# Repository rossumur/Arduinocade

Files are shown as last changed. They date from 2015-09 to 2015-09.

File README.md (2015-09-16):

#Arduinocade
Play retro color 8 bit games on your TV from an Arduino.

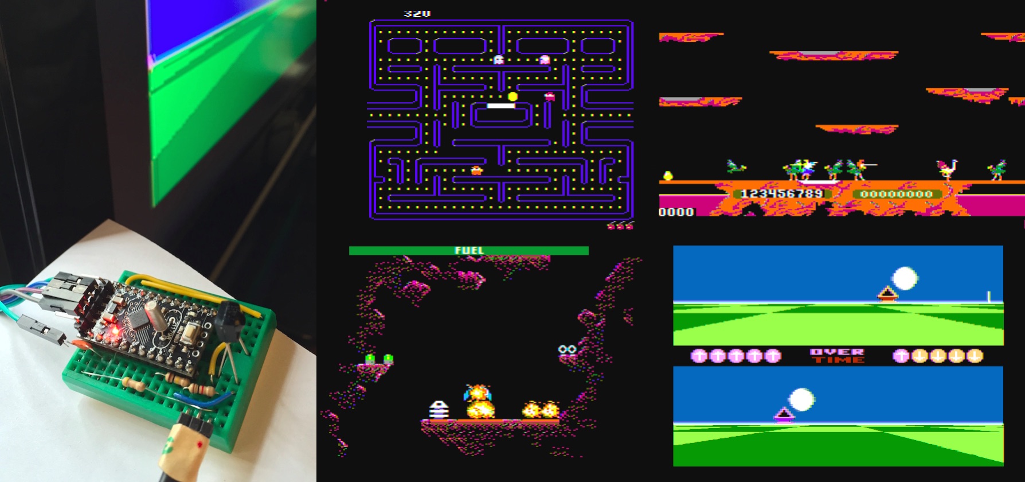
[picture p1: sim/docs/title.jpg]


**Arduinocade** features old school color 8 bit graphics (tiles, sprites, smooth scrolling, simple 3D) and sound (4 voice wavetable synthesis). All video and audio signals are generated with three resistors, an upgraded crystal and a little software. By overclocking the Arduino to 28.6363Mhz we can directly manipulate NTSC to generate 27 simultaneous colors. An IR receiver supports a wide variety of keyboards, joysticks and remote controls.

Video of Arduinocade in action at https://www.youtube.com/watch?v=nGIujZiEu_o

##Games
These games are sketches of what is possible on the Arduinocade hardware and a far from the polished pieces that inspired them.

###Ballblaster
A one-on-one sports style game inspired by the brilliant 1984 game Ballblazer. This uses a simple physics model and a 2D/3D rendering pipeline to produce 60fps animation. Try and grab the ball and shoot it into your opponent's goal.

###Pacman
What can I say? pakku pakku pakku.

###Jowst
Fly around on ostrich thingys. Poke each other with sticks. Nice example of using the sprite engine to generate lots of large multicolor sprites.

###Caverns of Titan
Homage to the Atari classic “Caverns of Mars”. Smooth scrolling, sprites and animation.

##Building the Hardware
Lots of different ways to build this beastie. The design is simple enough to build on a breadboard with a DIP Atmega328, alternatively you might want to add a 28.6363Mhz crystal to a $2 Arduino Pro Mini or even build on a custom PCB. 

###You will need
+ Arduino Pro Mini, Atmega328p or equivalent
+ 28.6363Mhz Crystal (from Adafruit, eBay etc)
+ RCA Audio/Video Cable (eBay)
+ 470ohm, 1k and 100k resistors
+ IR receiver TSOP38238,TSOP4838 or equivalent (Adafruit, Mouser etc)
+ IR Input device (see below)

```
        +----------------+
        |    arduino     |
        |    uno/pro     |
        |     28Mhz      |       5v <--+-+   IR Receiver
        |                |      GND <--|  )  TSOP4838
        |              8 |-------------+-+
        |                |
        |              6 |----[ 100k ]--------> AUDIO
        |                |
        |              9 |----[  1k  ]----+---> VIDEO
        |                |                |
        |              1 |----[ 470  ]----+
        |                |
        |              3 |
        |              2 |
        |                |
        +----------------+
```

###Mini Pro
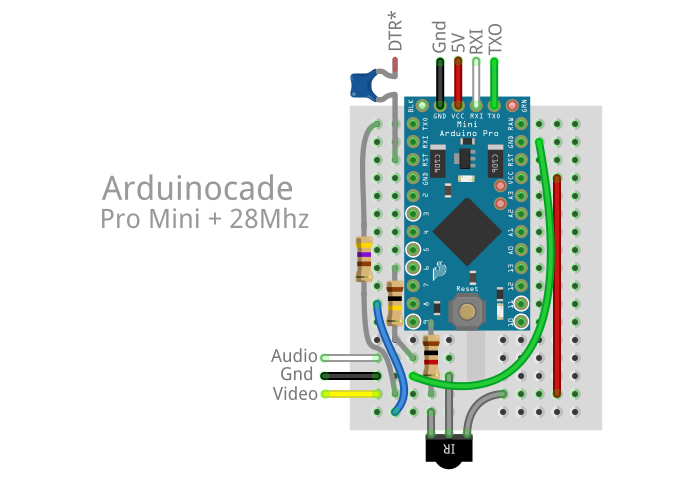
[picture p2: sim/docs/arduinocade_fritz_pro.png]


We will be upgrading the crystal/resonator on these boards from 16Mhz to 28.6363Mhz. The easiest ones to modify have the big silver cans on them. Others use a ceramic resonator which require a bit of SMD fiddling.

###Custom PCB
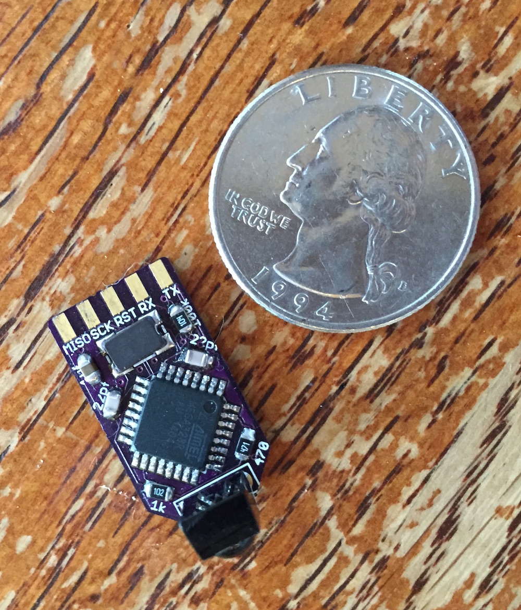
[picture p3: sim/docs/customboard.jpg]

If you want to get silly and build a custom board you can get a video console down to about the size of a quarter. Board and schematics can be found in `sim/docs/eagle`.

##Input Devices
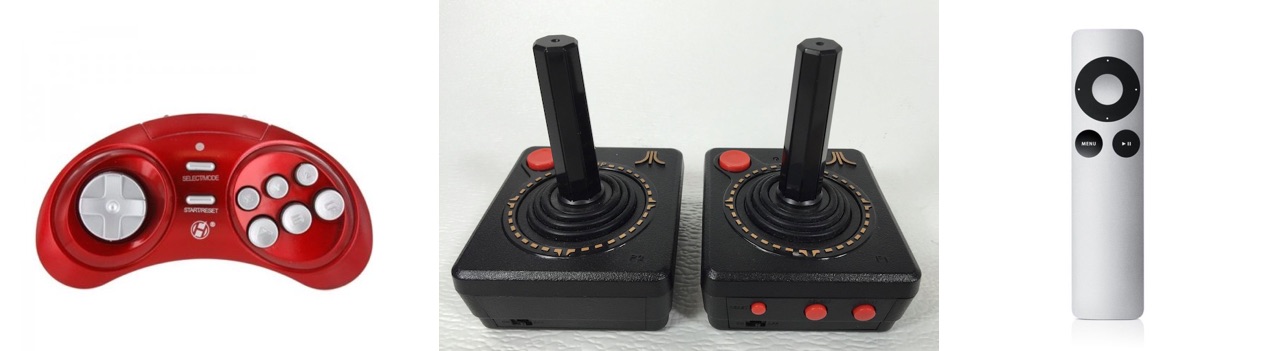
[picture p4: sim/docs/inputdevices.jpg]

*Retcon IR Controller, Atari Flashback 4 joysticks, Apple TV remote*

A number of IR input devices are supported. The IR Wireless Controllers from Atari Flashback 4 work well and have that classic joystick feel, as do the Retron IR controllers. These can be readily found on eBay for a few bucks. The Apple TV remote is also supported by you might feel a little silly. Edit config.h to select your input of choice.

##Upgrading the bootloader
If you want to use the Arduino IDE you should upgrade the bootloader to be able to work at 115200 baud with the faster crystal installed. The optiboot_atmega32_28.hex image has been rebuilt with F_CPU=28636363 and a slower watchdog reset so baud rate calculations will be correct for our overclocked device. Install the image with avrdude and your favorite ISP.
```
avrdude -c usbtiny -p atmega328p -e -u -U lock:w:0x3f:m -U efuse:w:0x05:m -U hfuse:w:0xDE:m -U lfuse:w:0xFF:m
avrdude -c usbtiny -p atmega328p -U flash:w:optiboot_atmega328_28Mhz.hex -U lock:w:0x0f:m
```
Once the modified optiboot is installed the device will behave like an Uno, so remember to select that from the boards menu in the Arduino IDE.

##Using the Arduino IDE

>**Note:**
>The current code does not work correctly with Arduino IDEs later than 1.5.6. Compiler optimizations in later versions interfere with hand timed loops in the video kernels. I will fix soon.

Copy the `Arduinocade` folder into the IDE libraries folder and relaunch IDE. You should be able to open the example games from *File->Examples->Arduinocade*. Edit the config.h file to enable or disable the custom `BALLBLASTER_GAME` kernel.

##How it works

###Video
Upgrading the crystal to 28.6363Mhz allows us to run at a multiple (8x CPU clock, 4x SPI output) of the NTSC subcarrier frequency. By spitting out bits in the right pattern at the right time we can generate NTSC colorburst and different colors based on the relative phase of the pattern.

Black (0000), White (1111), gray_5 (0101) and gray_10 (1010) don’t have a chroma component; the other 12 colors do. By inserting or skipping an extra nop in rendering kernel we can select between two different phases at the start of a line yielding 12+12+(black,white,gray) = 27 simultaneous colors on screen simultaneously. You can then add more by dithering etc.

###The Art of Artifacts
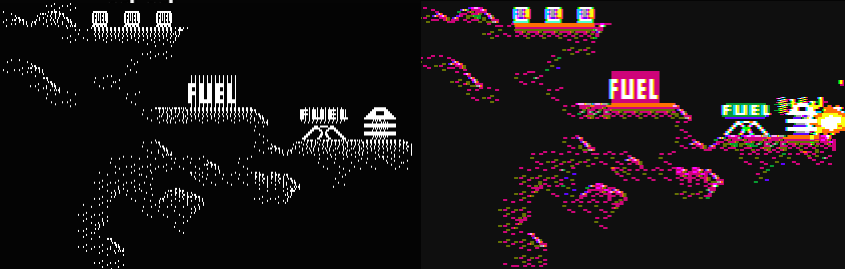
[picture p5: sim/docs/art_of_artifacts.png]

*Left - Pixels being emitted from the TX port, Right - Colors as they appear on NTSC* 

Every HSYNC interrupt the cpu emits a 3.57Mhz colorburst signal then sends pixel data from carefully timed tile or RLE video kernels. These are tricky to maintain in C, as helpful compiler optimizations often alter timing in unexpected ways. They probably all need to move to asm at some point. See note above.

The higher layer code uses a RLE format (BallBlaster) or tiles to represent game content. Because we don’t have enough memory for a full frame buffer individual lines of tiles and sprites are composed in a loop that is in lock step with the HSYNC interrupt.

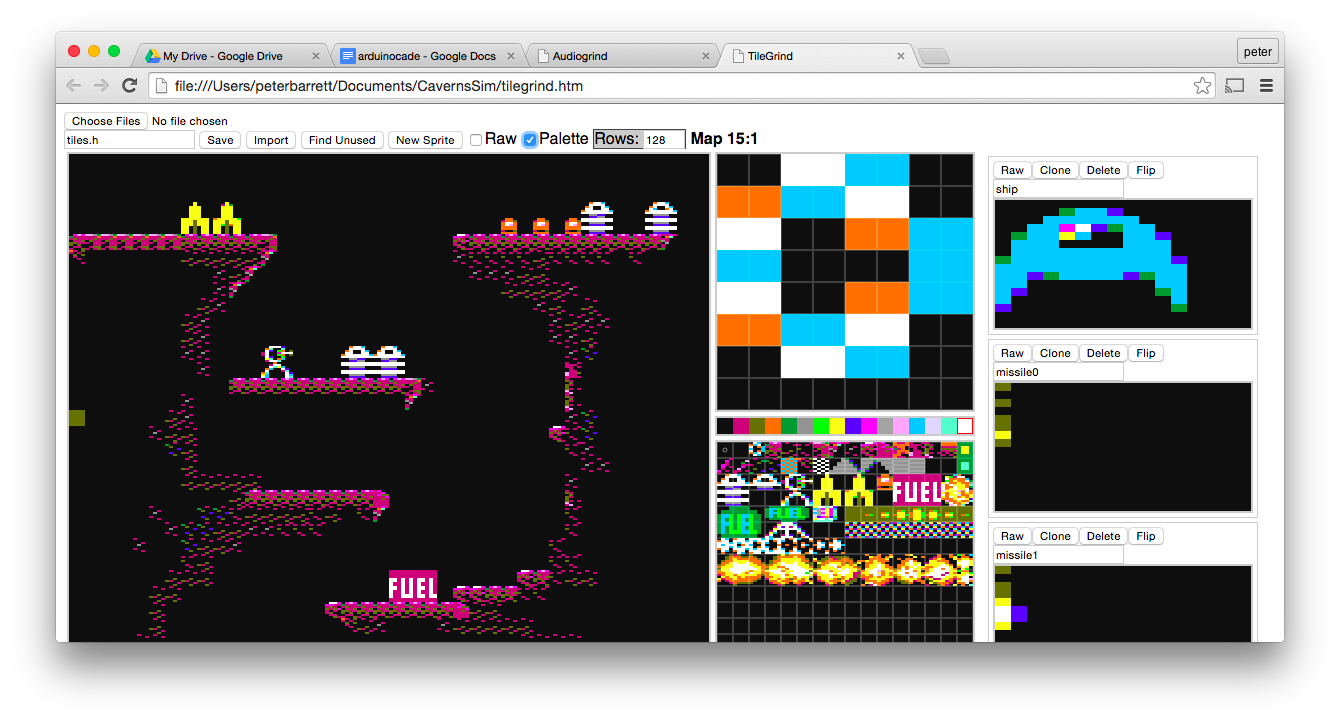
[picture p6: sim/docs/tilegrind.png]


TileGrind is a primitive html/javascript tool for generating color tiles and sprites. It can load and save C structs and understands the nature of NTSC color phase / artifacting. Its limitations vividly recreate the frustration of early graphics editing tools.

###Audio
The Audio driver has two parts.  The low level kernel runs every HSYNC, stepping each of the 4 voices though it’s wavetable, mixing the sampled voices together based on their current volume and emitting a sample to the PWM/resistor single bit DAC. This corresponds to a sample rate of 15734Hz.

The high level task runs every frame at 60Hz and adjusts envelope, modulates frequency of the underlying channels etc. It is responsible for parsing data structures containing music tracks and sound effects, adjusting volume envelopes and frequencies, swapping wavetables for different instruments etc.

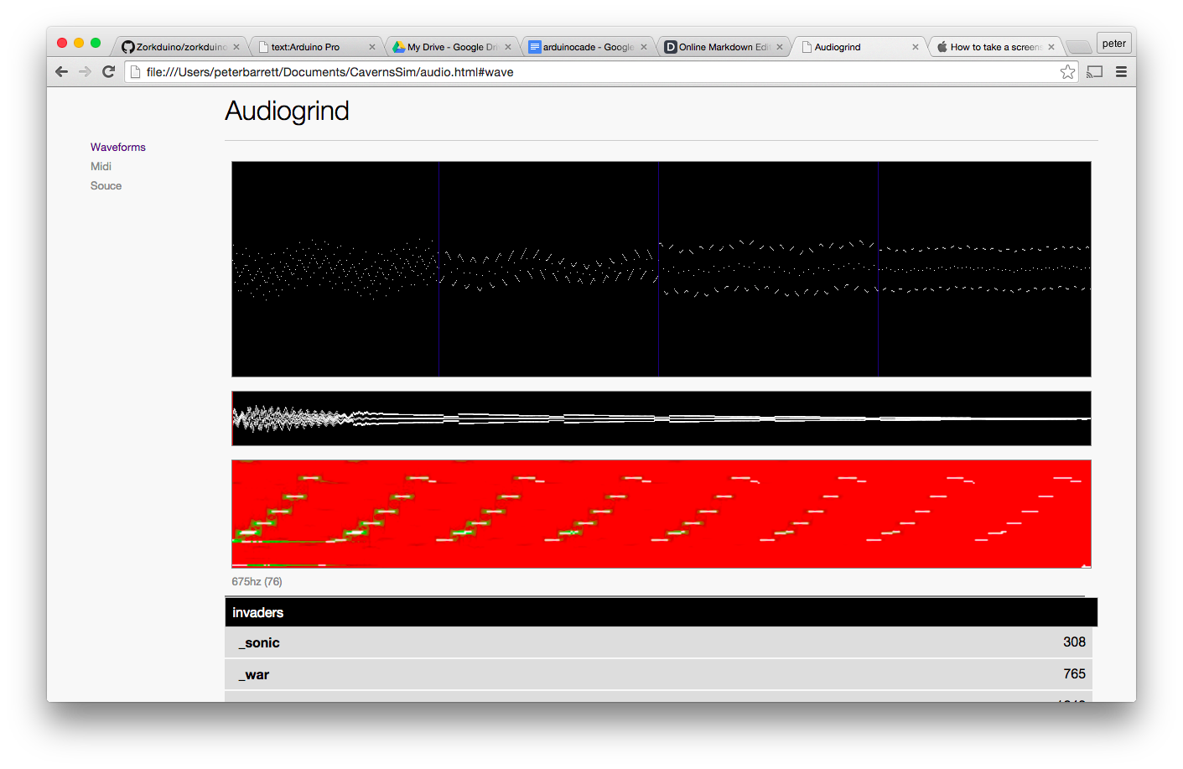
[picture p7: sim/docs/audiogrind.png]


AudioGrind is a primitive html/javascript audio editing tool is used to convert midi files to C struct data. It can also be used to reverse engineer classic gaming sound effects using a graphical spectrogram, without which it is nearly impossible to figure out how the effects are constructed - I’m talking to you Joust.

###IR input Joysticks, Keyboards etc
The GPIO attached to the IR sensor is sampled at HSYNC and fed to one of a number of IR decoders. The 15734Hz sample rate is enough to accurately parse nearly all IR protocols. For performance reasons only one is enabled at a time; check the #ifdefs in ir_input.cpp.

##So enjoy

Let me know if you have some fun with it.

Cheers
Rossum

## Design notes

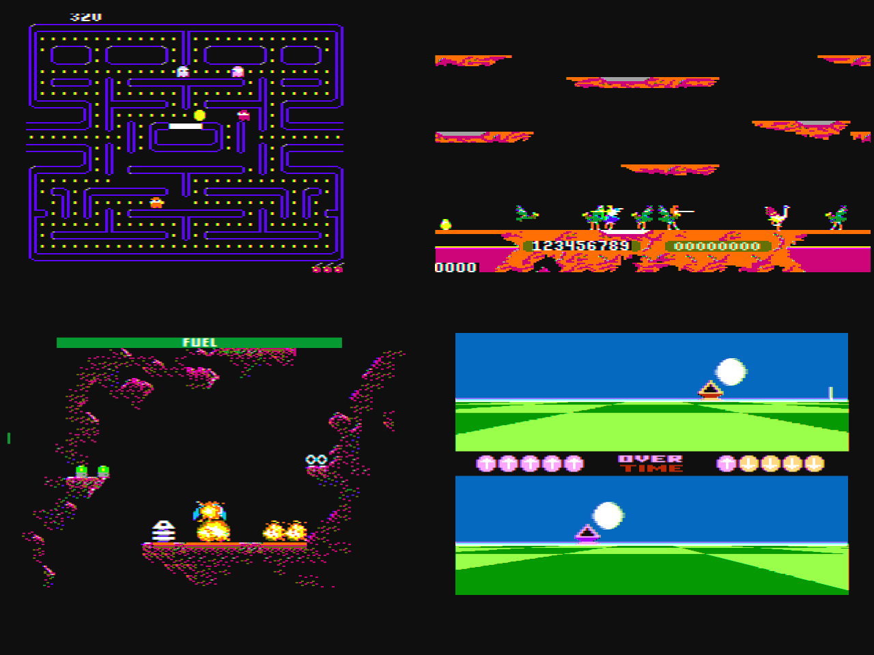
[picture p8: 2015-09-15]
sim/docs/screenshots.png

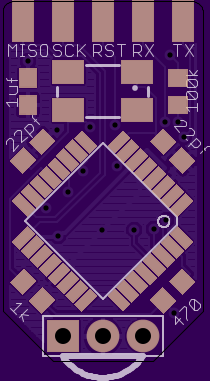
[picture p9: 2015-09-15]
sim/docs/pcb_top.png

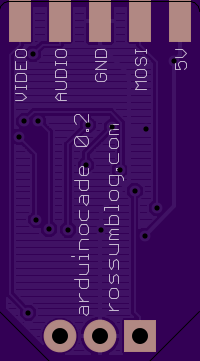
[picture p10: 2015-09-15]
sim/docs/pcb_bottom.png

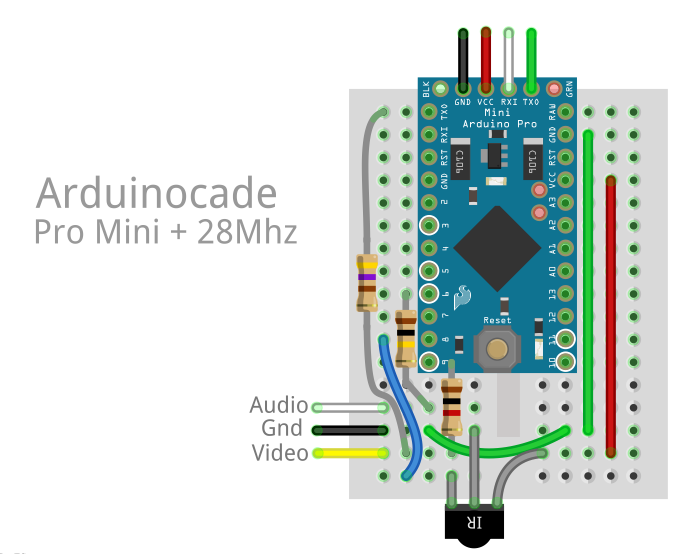
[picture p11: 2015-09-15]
sim/docs/arduinocade_friz_pro.png

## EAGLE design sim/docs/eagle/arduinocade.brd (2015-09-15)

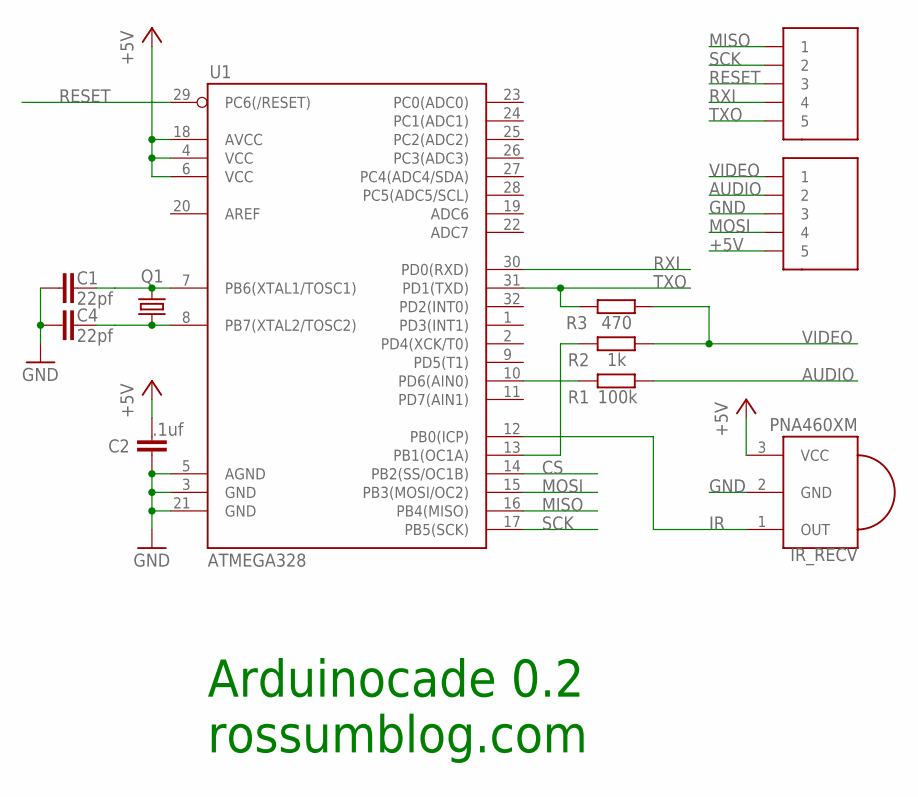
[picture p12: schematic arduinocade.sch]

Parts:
C1, C4: 22pf; C0603
C2: .1uf; C0603
IR_RECV: PNA460XM
Q1: CRYSTALCTS406; CTS406
R1: 100k; R0603
R2: 1k; R0603
R3: 470; R0603
U1: ATMEGA328; TQFP32-08
U$2, U$3: EDGE5

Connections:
+5V: C2.1, U1.4 (VCC), U1.6 (VCC), U1.18 (AVCC), U$3.5
AUDIO: R1.2, U$3.2
CS: U1.14 (PB2(SS/OC1B))
GND: C1.2, C2.2, C4.2, IR_RECV.2 (GND), U1.3 (GND), U1.5 (AGND), U1.21 (GND), U$3.3
IR: IR_RECV.1 (OUT), U1.12 (PB0(ICP))
MISO: U1.16 (PB4(MISO)), U$2.1
MOSI: U1.15 (PB3(MOSI/OC2)), U$3.4
unnamed: C4.1, Q1.1, U1.8 (PB7(XTAL2/TOSC2))
unnamed: C1.1, Q1.3 (2), U1.7 (PB6(XTAL1/TOSC1))
unnamed: R2.1, U1.13 (PB1(OC1A))
unnamed: R1.1, U1.10 (PD6(AIN0))
RESET: U1.29 (PC6(/RESET)), U$2.3
RXI: U1.30 (PD0(RXD)), U$2.4
SCK: U1.17 (PB5(SCK)), U$2.2
TXO: R3.1, U1.31 (PD1(TXD)), U$2.5
VCC: IR_RECV.3 (VCC)
VIDEO: R2.2, R3.2, U$3.1

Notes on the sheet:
Arduinocade 0.2
rossumblog.com

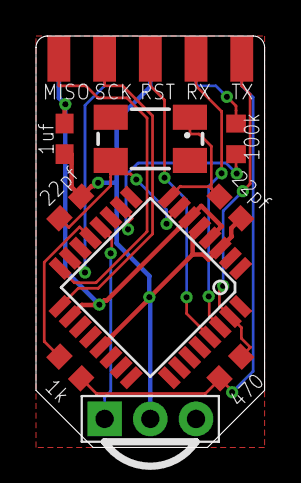
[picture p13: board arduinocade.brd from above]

Board: 2 copper layers, 12.7 x 22.9 mm, 11 parts (1 on the bottom side), 15 nets.

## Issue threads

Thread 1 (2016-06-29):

ATMEGA328PU

fredericplante, 2016-06-29:
Hey it's not really an issue, but before getting 28Mhz christal, I wounder, will that work on the DIP version of the ATMEGA328, or does it need to be done on a mini?

jameswilddev, 2020-12-31:
Should work on a DIP 328p:

```
##Building the Hardware Lots of different ways to build this beastie. The design is simple enough to build on a breadboard with a DIP Atmega328, alternatively you might want to add a 28.6363Mhz crystal to a $2 Arduino Pro Mini or even build on a custom PCB.
```

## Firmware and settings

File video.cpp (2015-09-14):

/* Copyright (c) 2010-2015, Peter Barrett
 **
 ** Permission to use, copy, modify, and/or distribute this software for
 ** any purpose with or without fee is hereby granted, provided that the
 ** above copyright notice and this permission notice appear in all copies.
 **
 ** THE SOFTWARE IS PROVIDED "AS IS" AND THE AUTHOR DISCLAIMS ALL
 ** WARRANTIES WITH REGARD TO THIS SOFTWARE INCLUDING ALL IMPLIED
 ** WARRANTIES OF MERCHANTABILITY AND FITNESS. IN NO EVENT SHALL THE AUTHOR
 ** BE LIABLE FOR ANY SPECIAL, DIRECT, INDIRECT, OR CONSEQUENTIAL DAMAGES
 ** OR ANY DAMAGES WHATSOEVER RESULTING FROM LOSS OF USE, DATA OR PROFITS,
 ** WHETHER IN AN ACTION OF CONTRACT, NEGLIGENCE OR OTHER TORTIOUS ACTION,
 ** ARISING OUT OF OR IN CONNECTION WITH THE USE OR PERFORMANCE OF THIS
 ** SOFTWARE.
 */

// Video output, audio tone generation and IR keyboard scanning events

#include "config.h"
#include "video.h"

// PORT B
#define SYNC_PIN    1
#define IR_PIN      0

// PORT D
#define AUDIO_PIN       6
#define PS2_CLOCK_PIN   3
#define PS2_DATA_PIN    2
#define VIDEO_PIN       1

// Color clock frequency is 315/88
// CPU Mhz is 315/11
// 455/2 color clocks per line
// HSYNCH period is 44/315*455 or 63.55555..us
// Field period is 262*44/315*455 or 16651.5555us

// ~1820 cpu clocks per line at 28.6363Mhz
#define USEC(_x)         (((_x)*28.6363)-1)
#define TICKS_SCANLINE   (1824-1)
#define TICKS_HSYNC      USEC(4.7)
#define TICKS_LONG_HSYNC USEC(63.555-4.7)
#define TICKS_HBLANK     USEC((4.7+1.5))
#define TICKS_INTERRUPT  USEC(4.05)  // late as possible 4.2

#define TEXT_ROWS 24
#define TEXT_COLS 40
#define BLANK_LINES 40
#define ACTIVE_LINES (TEXT_ROWS*8)

#define STATE_VBLANK  0
#define STATE_PRE     1
#define STATE_ACTIVE  2
#define STATE_POST    3

// does not do halfline sync during blanking
//__attribute__((section(".progmem.data")))
PROGMEM
const uint8_t v_lines[] = { 3,BLANK_LINES,ACTIVE_LINES,262-(3+BLANK_LINES+ACTIVE_LINES) };

// Video State
volatile uint8_t v_state = 0;
volatile uint8_t v_count = 0;
uint8_t v_vbicountdown = 0;

// TODO
uint8_t v_framecounter;
uint16_t _linecount;

// Audio state
uint8_t a_count = 0;
uint8_t a_freq = 0;
uint8_t a_cycles = 0;

// IR state
uint8_t ir_last = 0;
uint8_t ir_count = 0;

//==========================================================
//==========================================================
//  Webtv keyboard

// Report changes on IR pin to keyboard handler
// t is HSYNCH ticks
void keyboardIREvent(uint8_t t, uint8_t v);

//==========================================================
//==========================================================
// PS2 keyboard

void enable_ps2();
void disable_ps2();

//==========================================================
//==========================================================
//  audio for keyboard/io feedback

void audio_beep(uint8_t freq, uint8_t cycles)
{
    a_freq = freq;
    a_cycles = cycles;
    a_count = freq;
}

//==========================================================
//==========================================================
// Video buffering state machine

#define VROWS_BUFS   4 // POWER OF 2
#define VROWS_MASK (VROWS_BUFS-1)

volatile VRow* _vrows[VROWS_BUFS];
volatile uint8_t _vread;
volatile uint8_t _vwrite;

// TODO: 0..ACTIVE_LINES?
int video_current_line()
{
    if (v_state == STATE_ACTIVE)
        return ACTIVE_LINES-v_count;
    return v_state == STATE_POST ? ACTIVE_LINES : -1;
}

uint8_t video_queue_count()
{
    return _vwrite-_vread;
}

void video_enqueue(VRow* row)
{
    while (_vwrite-_vread == VROWS_BUFS)
        ; // Queue is full
    _vrows[_vwrite++ & VROWS_MASK] = row;
}

//==========================================================
//==========================================================
//  Video ISR

static void inline tick_align(uint8_t tick)
{
    __asm__ __volatile__ (
                          "sub	%[tick], %[tcnt1l]\n"
                          "0: subi	%[tick], 3\n"
                          "brcc	0b\n"
                          "cpi      %[tick],-3\n"
                          "breq     1f\n"
                          "cpi      %[tick],-2\n"
                          "brne     .\n"
                          "1:\n"
                          :: [tick] "a" (tick),
                          [tcnt1l] "a" (TCNT1L)
                          );
}

void rle_blit(VRowRLE* row)
{
    UDR0 = 0;
    uint8_t run = row->skip;
    uint8_t x = row->width;
    const uint8_t* rle = row->rle;
    if (!rle)
        return;
    uint8_t color = 0;
    
    //  16 clocks thru all paths
    for(;;)
    {
        UDR0 = color;          // 2
        asm ("nop");           // 1
        if (!--run)            // 1+(1:3)
        {
            if (!x)              // 1+(1:3)
                break;
            run = rle[0];        // 2
            color = rle[1];      // 2
            rle += 2;            // 2 (stupid)
            x-= run;             // 1
            continue;            // 3
        }
        asm ("nop");            // 1
        asm ("nop");            // 1
        asm ("nop");            // 1
        asm ("nop");            // 1
        asm ("nop");            // 1
        asm ("nop");            // 1
        asm ("nop");            // 1
        asm ("nop");            // 1
    }
}

#define BUFFER_SIZE 1350
#define MAX_LINE_BYTES 64
extern volatile uint8_t* _read_rle;
extern uint8_t _bb_buf[BUFFER_SIZE + MAX_LINE_BYTES];

// Sorry for the assembly
// Touchy little bit of code that draws runs color/run pairs
// maintains 16 clocks/pixel pair through all paths

void blit_rle()
{
  PIXEL_OUT(0x00);
  uint8_t* src = (uint8_t*)_read_rle;
  asm(
"        sts	0x00C6, r1\n"   // PIXELOUT(0)
"        sts	0x00C6, r1\n"   // PIXELOUT(0)
"        ldd	r18, Z+3\n"     // color = src[3]
"        ldi	r19, 0x01\n"    // run = 1
"        ldi	r25, 144/2\n"   // x = 72
"        sts	0x00C6, r1\n"   // PIXELOUT(0)
"        sts	0x00C6, r1\n"   // PIXELOUT(0)

"0:\n"
"        ld	r19, Z+\n"    // 5     2 run
"        ld	r18, Z+\n"    // 7     2 c
"        cp	r1, r19\n"    // 9     1 if (run > 0)
"        brlt	1f\n"         // 10    1:2  goto even

// odd
"        mov	r24, r18\n"     // 11 last |= c & 0x0F;
"        andi	r24, 0x0F\n"    // 12
"        or	r20, r24\n"     // 13
"        sts	0x00C6, r20\n"  // 14 PIXEL_OUT(last);
"        subi	r25, 0x01\n"    // 0 if (!--x)
"        breq	99f\n"          // 1  goto l99;
"        andi	r19, 0x7F\n"    // 2 if (!(run &= 0x7F))
"        breq   0b\n"           // 3  goto l0;
"        rjmp   33f\n"          // 4 goto loop

//  even
"1:      \n"
"        mov	r20, r18\n"    // 13 last = c;
"        andi	r20, 0xF0\n"   // 14 last &= 0xF0
"        sts	0x00C6, r18\n" // 14 PIXEL_OUT(c); 
"        subi	r25, 0x01\n"   // 0  if (!--x)
"        breq	99f\n"         // 1   goto l99;
"        subi	r19, 0x01\n"   // 2  if (!--run)
"        breq   0b\n"          // 3   goto l0;
"        rjmp   33f\n"         // 4  goto loop
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

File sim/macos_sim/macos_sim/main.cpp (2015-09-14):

//
//  main.cpp
//
//  Created by Peter Barrett on 2/17/13.
//  Copyright (c) 2013 Peter Barrett. All rights reserved.
//

#include <iostream>
#include <stdio.h>
#include <SDL.h>
#include <SDL_audio.h>
#include <pthread.h>
#include "math.h"
#include "unistd.h"

__attribute__((weak))
void video_blanking(uint8_t line) {};

__attribute__((weak))
void video_begin_post(uint8_t phase) {}

// Player 1 up,down,left,right space
// Player 2 w z a d s

//================================================================================
//================================================================================
//  Select one of the following

#define BALLBLASTER_GAME
#ifdef BALLBLASTER_GAME
#include "ballblaster/ballblaster.ino"
#else
#include "pacman/pacman.ino"
//#include "jowst/jowst.ino"
//#include "titan/titan.ino"
#endif

//================================================================================
//================================================================================
#include "video.h"

SDL_Surface *screen;
#define SDL_WIDTH   640
#define SDL_HEIGHT  (VROWS*8*2)
#define SDL_DEPTH   32

#define VROWS_BUFS   8 // POWER OF 2
#define VROWS_MASK (VROWS_BUFS-1)

VRow* _vrows[VROWS_BUFS];
volatile uint8_t _vread;
volatile uint8_t _vwrite;
int v_current_line = 192;

//================================================================================
//================================================================================
//  ntsc color generation from phase pixels

// LINE BUFFER
#define CHROMA_WIDTH 160
uint8_t _buf[CHROMA_WIDTH/2*2]; // sLop

int bitat(int pos)
{
    if (pos < 0)
        pos = 0;
    if (pos >= CHROMA_WIDTH*4)
        pos = CHROMA_WIDTH*4-1;
    return _buf[pos >> 3] & (0x80 >> (pos & 7)) ? 1 : 0;
}

static int gamma(float f)
{
    if (f < 0)
        return 0;
    f = pow(f, 2.2f/2.0f);
    if (f > 1)
        return 255;
    return f*255;
}

#ifdef BALLBLASTER_GAME
#define BURST_PHASE 1.0f
#else
#define BURST_PHASE 1.5f
#endif

//  4 phases, 4 bits ,0x11 colorburst
int _rgb_table[256];
int _rgb_table_inited = false;
int make_rgb_table(int phz, int bits)
{    
    float y = 0;
    float i = 0;
    float q = 0;
    for (int p = 0; p < 4; p++)
    {
        float phase = M_PI/2*(BURST_PHASE + phz++);    // 4 phases, 4 bits ,0x11 colorburst
        float luma = (bits & 0x8) ? 0.94f : 0.06f;
        y  =  y + luma;
        i  =  i + luma * cos(phase);
        q  =  q + luma * sin(phase);
        bits <<= 1;
    }
    y /= 3;
    i /= 2.5;
    q /= 2.5; // punch up saturation a bit
    
    int r = gamma(y +  0.946882f*i +  0.623557f*q);
    int g = gamma(y + -0.274788f*i + -0.635691f*q);
    int b = gamma(y + -1.108545f*i +  1.709007f*q);
    return (b << 24) | (g << 16) | (r << 8) | 0xFF;
}

int get_rgb(int begin)
{
#if 0
    for (int i = 0; i < 16; i++)
    {
        uint32_t rgb = make_rgb_table(0,i) >> 8;
        uint8_t r = rgb;
        uint8_t g = rgb>>8;
        uint8_t b = rgb>>16;
        printf("\"#%02X%02X%02X\",\n",r,g,b);
    }
     for (int i = 0; i < 16; i++)
     {
         uint32_t rgb = make_rgb_table(0,i) >> 8;
         uint8_t r = rgb;
         uint8_t g = rgb>>8;
         uint8_t b = rgb>>16;
         printf("0x%02X%02X%02X,\n",r,g,b);
     }
#endif
    
    int bits = 0;
    int p = 4;
    while (p--)
        bits = (bits << 1) | bitat(begin++);
    int phz = begin & 3;                // 4 bits/4 phases
    
    if (!_rgb_table_inited) {
        _rgb_table_inited = true;
        for (int i = 0; i < 256; i++)
            _rgb_table[i] = make_rgb_table(i >> 4,i & 0xF);
    }
    return _rgb_table[(phz << 4) | bits];
}

#if 0
static void bars()
{
    for (int x = 0; x < CHROMA_WIDTH/2; x++)
    {
        int p = x/5;
        _buf[x] = p | (p << 4);
    }
}

static void c256()
{
    int color = v_current_line/12;
    color &= 0xF;
    for (int x = 0; x < CHROMA_WIDTH/2; x++)
    {
        int p = x/3;
        if (v_current_line & 1)
            _buf[x] = color | (p << 4);
        else
            _buf[x] = p | (color << 4);
    }
}
#endif

uint8_t _line_count = 0;
void render_line_ntsc(uint8_t line, int* dst)
{    
    //bars();
    //c256();
    //bb2(line);

    for (int pp = 0; pp < 4; pp++)
    {
        for (int x = 0; x < CHROMA_WIDTH; x++)
        {
            int center = x*4+pp;
            dst[center] = get_rgb(center - 2);
        }
    }
    _line_count++;
}


// TODO: 0..ACTIVE_LINES?
int video_current_line()
{
    return v_current_line;
}

uint8_t video_queue_count()
{
    return _vwrite-_vread;
}

void flush_video(bool cb = false);
void video_enqueue(VRow* row)
{
    while (_vwrite-_vread == VROWS_BUFS)
        ; // Queue is full
    _vrows[_vwrite++ & VROWS_MASK] = row;
    flush_video();
}

#ifdef BALLBLASTER_GAME

#define BUFFER_SIZE 1350
#define MAX_LINE_BYTES 64

extern volatile uint8_t* _read_rle;  // rle blit buffer
extern uint8_t _bb_buf[BUFFER_SIZE+MAX_LINE_BYTES];

void blit_rle()
{

    volatile uint8_t* src = _read_rle;
    //printf("R:%d\n",_read_rle-_bb_buf);
    int8_t run;
    uint8_t c,last;
    uint8_t x = 72;
    last = src[3];  // Single pixel run at start of line
l0:
    run = *src++;       // 6 2
    c = *src++;         // 8 2
   // printf(" %02X:%02X",(uint8_t)run,c);
    if (run > 0)        // 9 1
        goto even;      // 10 1:3
odd:
    last |= c & 0x0F;   // 11 2
    PIXEL_OUT(last);    // 13 2
    last = c;           // bad if next is odd
    if (!--x)           // 0 1
        goto l99;       // 1 1:3
    if (!(run &= 0x7F)) // 2 1
        goto l0;        // 3 1:3    // only bad here
    goto loop;          // 4 3

even:
    PIXEL_OUT(c);       // 13 2
    last = c & 0xF0;    // 15 1
    if (!--x)           // 0 1
        goto l99;       // 1 1:3
    if (!--run)         // 2 1
        goto l0;        // 3 1:3  // 16
    goto loop;          // 4 3
    
noploop:
    asm("nop"); // 4
    asm("nop"); // 5
    asm("nop"); // 6
    
loop:
    last = c & 0xF0;    // 7 2
    --x;                // 9 1
    asm("nop");         // 10
    asm("nop");         // 11
    asm("nop");         // 12
    PIXEL_OUT(c);       // 13 2
    asm("nop");         // 15
    if (--run)          // 0 1
        goto noploop;   // 1 1:3
    if (x)              // 2 1
        goto l0;        // 3 1:3
l99:
    _read_rle = src;    // No wrapping
}

//
// Strip in middle (good advice)
extern
uint8_t _cellmap[32*2];
extern
const uint8_t* _celltiles;

void blit_tiles(uint8_t line)
{
    const uint8_t* font = _celltiles + ((line & 7) << 8);   // 128 chars in tilemap
    uint8_t* src = _cellmap;
    if (line >= 8)
        src += 32;

    for (int i = 0; i < 4; i++)
        PIXEL_OUT(0x00);

    uint8_t n = 32;
    do
    {
        uint8_t c = *src++;
        const uint8_t* f = font+c+c;
        if (c == 0)                 // 2 or 5
            break;
        PIXEL_OUT(pgm_read_byte(f++));
        PIXEL_OUT(pgm_read_byte(f++));
    } while(--n);  // 4
}

__attribute__((weak))
void video_active(uint8_t line)
{
    if (line < 87 || line >= (87+18))   // 18 lines in the middle
    {
        //printf("%d: ",line);
        blit_rle();
        //printf("\n");
    }
    else {
        line -= 88;
        if (line < 16)
            blit_tiles(line);
        else
        {
            for (int i = 0; i < 80; i++)
                PIXEL_OUT(0);
        }
        video_begin_post(1);
    }
}
#endif

void render_line(uint8_t line, int* dst)
{
    //UDR0 = 0;
    VRow* r = _vrows[_vread & VROWS_MASK];    // get the next row
    VRowTiles* row = (VRowTiles*)r;
    if (line == r->y)
        _vread++;   // y where line is removed
    
    line = (line + row->v_scroll) & 7;
    const uint8_t* font = row->rom_font + (line << 1)*row->rom_font_count;
    const uint8_t* ram_font = row->ram_font + (line << 1);
    uint8_t ram_start = row->rom_font_count;
    
    uint8_t* src = row->tiles;
    uint8_t* d = _buf;
    
    // 40 character output
    uint8_t a = VCOLS;
    do
    {
        uint8_t c = *src++;
        if (c < ram_start)
        {
            if (c == 0)
            {
                memset(d,0,2*a);    // early out
                break;
            }
            const uint8_t* f = font+(c<<1);
            *d++ = *f++;
            *d++ = *f++;
        } else {
            c -= ram_start;
            //c <<= 2;
            const uint8_t* s = ram_font + (c<<4); // can live without shift (todo: > 16)
            *d++ = *s++;
            *d++ = *s++;
        }
    } while (--a);
    
    render_line_ntsc(line,dst);
}

void video_start()
{
}

//================================================================================
//================================================================================

bool _running;
bool running()
{
    return _running;
}

void setup();
void loop();

int gameThread(void* p)
{
    setup();
    while (_running)
        loop();
    _running = false;
    return 0;
}

unsigned int ir_data;
unsigned char ir_count;
int _phase = 0;
int _repeat = 0;
uint8_t v_framecounter = 0;
int _buf_x = 0;
void PIXEL_OUT(uint8_t p)
{
    _buf[_buf_x++] = p;
}

void music_kernel();
void flush_video(bool cb)
{
    //bool doubleLine = true;
    if(SDL_MUSTLOCK(screen))
    {
        if(SDL_LockSurface(screen) < 0) return;
    }
    
    if (v_current_line == 192)
    {
        //music_kernel();
        v_current_line = 0;
#ifdef BALLBLASTER_GAME
        _read_rle = _bb_buf;
#endif
        video_begin_post(0);
        for (int i = 0; i < 40; i++)
            video_blanking(i);
    }
    
    int rowBytes = screen->pitch/4;
    while ((_vread - _vwrite) || cb)
    {
        int* dst = (int*)screen->pixels + rowBytes*(v_current_line*2 + (v_framecounter & 1));
        if (cb) {
            _buf_x = 0;
#ifdef BALLBLASTER_GAME
            video_active(v_current_line);
#endif
            render_line_ntsc(v_current_line,dst);
            cb = false;
        } else
            render_line(v_current_line,dst);
        //if (doubleLine)
        //    memcpy(dst+rowBytes,dst,rowBytes*4);
        v_current_line++;
        if (v_current_line == 192)
            break;
    }
    
    if(SDL_MUSTLOCK(screen)) SDL_UnlockSurface(screen);
    
    if (v_current_line == 192)
    {
        v_framecounter++;
        _vread = _vwrite;
        SDL_Flip(screen);
    }
    
    /*
    if (_key && (++_repeat > 6))
    {
        ir_data = _key;
        ir_count = 32;
        _repeat = 0;
    }
     */
}

//============================================================================
//============================================================================
//  Audio sim

#define AUDIO_BUFFER 1024
#define AUDIO_MASK (AUDIO_BUFFER-1)
unsigned char _audio[AUDIO_BUFFER];
int _read = 0;
int _write = 0;
void AUDIO_OUT(int p)
{
    _audio[_write++ & AUDIO_MASK] = p;
}

extern uint8_t _mix;
void AUDIO_STEP();
void step_audio()
{
    for (int i = 0; i < 262; i++)
    {
        AUDIO_STEP();
        AUDIO_OUT(128-_mix);
    }
}

void audio_callback(void *userdata, Uint8 *stream, int len)
{
    step_audio();
    short* s = (short*)stream;
    len >>= 1;
    for (int i=0;i<len;i++)
    {
        if (_read >= _write)
            break;
        *s++ = (_audio[_read++ & AUDIO_MASK]-128) << 8;
      //  if ((_read & 0x3FFF) == 0)
      //      fprintf(stderr,"bfu %d\n",_write-_read);
    }
}

//============================================================================
//============================================================================
//  Joystickwsx sim

uint16_t _joy[2];
uint16_t* readJoy()
{
    return _joy;
}

void maskkey(bool down, int mask, uint8_t key)
{
    if (down)
        _joy[key] |= mask;
    else
        _joy[key] &= ~mask;
}

void keymask(int key, bool down)
{
    switch (key) {
        case SDLK_UP:       maskkey(down,UP,0); break;
        case SDLK_DOWN:     maskkey(down,DOWN,0); break;
        case SDLK_RIGHT:    maskkey(down,RIGHT,0); break;
        case SDLK_LEFT:     maskkey(down,LEFT,0); break;
        case SDLK_SPACE:    maskkey(down,FIRE,0); break;
            
        case SDLK_w:        maskkey(down,UP,1); break;
        case SDLK_z:        maskkey(down,DOWN,1); break;
        case SDLK_a:        maskkey(down,LEFT,1); break;
        case SDLK_d:        maskkey(down,RIGHT,1); break;
        case SDLK_s:        maskkey(down,FIRE,1); break;
        default:break;
    }
}

int main(int argc, char* argv[])
{
    SDL_Event event;
    
    int keypress = 0;
    if (SDL_Init(SDL_INIT_VIDEO | SDL_INIT_AUDIO) < 0 ) return 1;
    
    if (!(screen = SDL_SetVideoMode(SDL_WIDTH, SDL_HEIGHT, SDL_DEPTH, 0)))
    {
        SDL_Quit();
        return 1;
    }
    
    _running = true;
    SDL_Thread *thread;
    thread = SDL_CreateThread(gameThread, NULL);
    
    SDL_AudioSpec desired = {0};
    SDL_AudioSpec obtained = {0};

    desired.freq= 15734; // NTSC line rate
    desired.format=AUDIO_S16;
    desired.channels=1;
    desired.samples=262;
    desired.callback=audio_callback;
    
    /* Open the audio device */
    if ( SDL_OpenAudio(&desired, &obtained) < 0 ){
        fprintf(stderr, "Couldn't open audio: %s\n", SDL_GetError());
        exit(-1);
    }
    SDL_PauseAudio(0);
    SDL_EnableKeyRepeat(1,30);

    while(!keypress)
    {
        while(SDL_PollEvent(&event))
        {
            switch (event.type)
            {
                case SDL_QUIT:
                    keypress = 1;
                    break;
                case SDL_KEYUP:
                    keymask(event.key.keysym.sym,0);
                    break;
                    
                case SDL_KEYDOWN:
                    keymask(event.key.keysym.sym,1);
                    break;
            }
        }
    }
    _running = false;
    SDL_WaitThread(thread, NULL);
    SDL_Quit();
    return 0;
}

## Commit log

2015-09-14 Arduinocade initial checkin
2015-09-15 Adding docs
    [arduinocade.brd, arduinocade.sch]
2015-09-15 Additional images
    [arduinocade_pro_mini.fzz]
